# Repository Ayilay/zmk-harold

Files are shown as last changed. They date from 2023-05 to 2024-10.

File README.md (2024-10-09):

# Harold Keyboard

A fully-split fully-wireless keyboard that I made for myself. Powered by ZMK, a 750mAh LiPo, and an Seeeduino XIAO NRF52840.

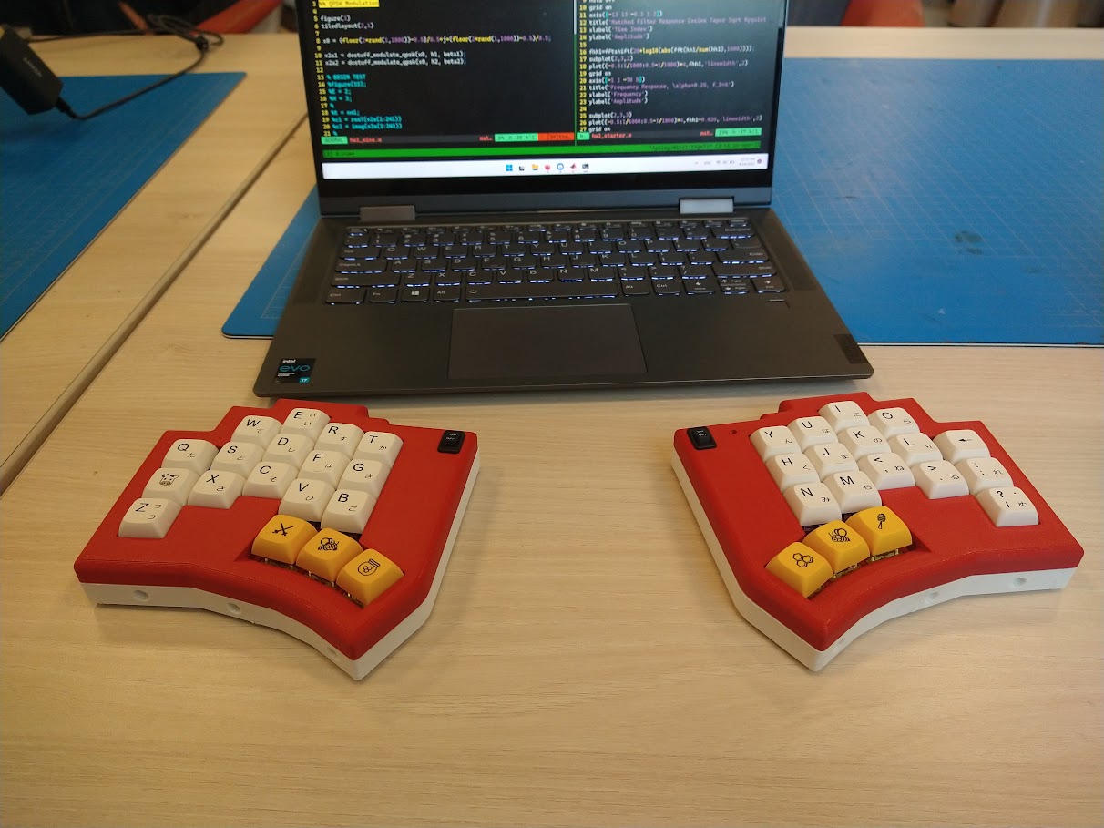
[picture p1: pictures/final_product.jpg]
Final Product


## Repository Files

`config` has the zmk config files.
`hardware/ergogen` has the [Ergogen](https://github.com/ergogen/ergogen) files that were used to generate PCB Layout.
`hardware/pcb` has the KiCAD PCB files.

## Pictures

This is my favorite use case: Comfy Coding
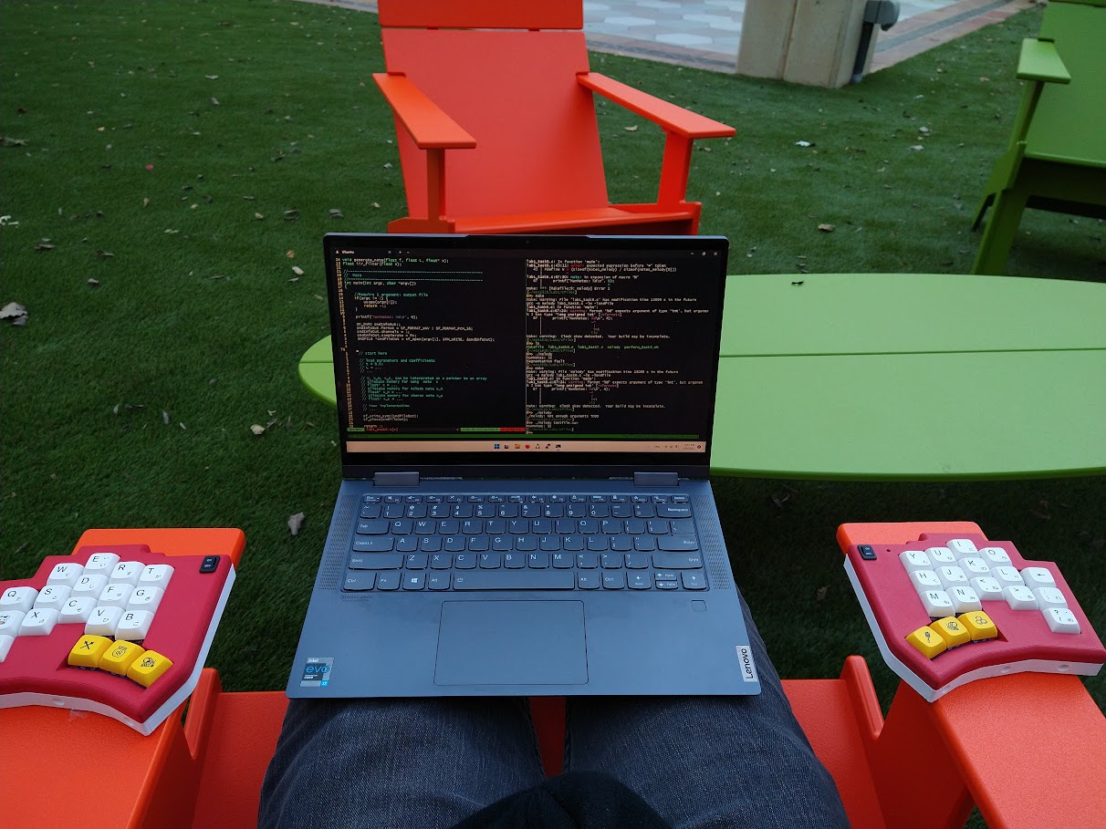
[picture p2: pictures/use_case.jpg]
Use Case


This is what it looks like under the hood:
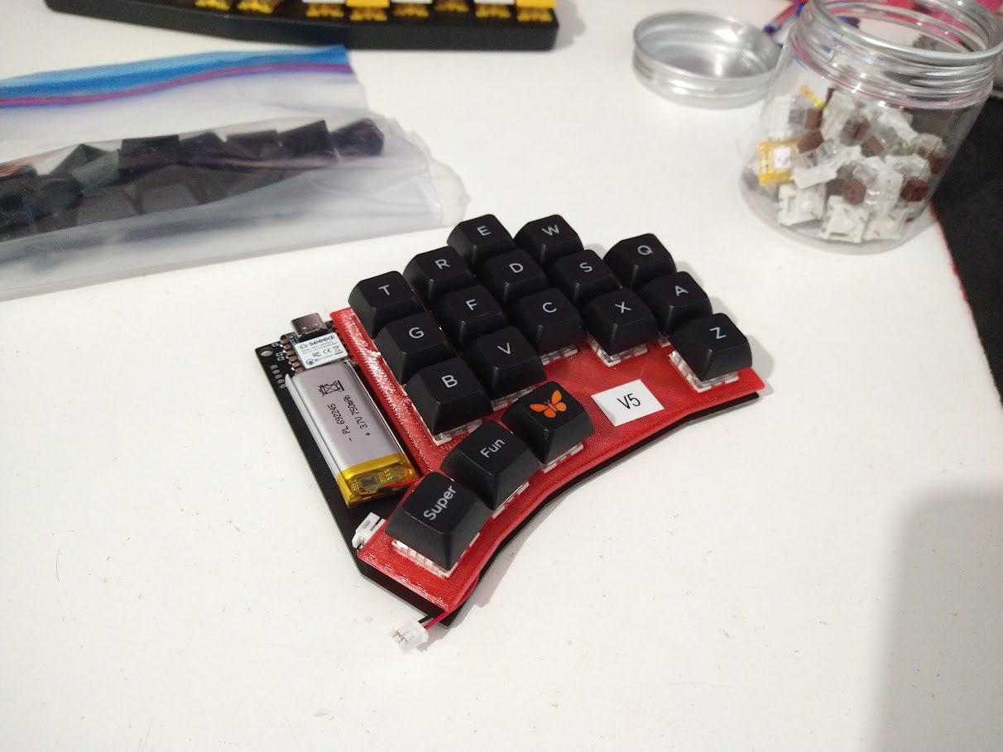
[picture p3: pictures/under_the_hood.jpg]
Under the hood


## FAQ

#### WOA That's so cool! You should sell these!
No. I made this keyboard to fill a very particular need.
This keyboard was highly customized for myself. There are plenty of other companies out there
with exceptional split wireless keyboards.

#### Doesn't the battery run out?
Many wireless keyboards I've seen use a dinky 250 mAh LiPo battery, because it's very small.
Luckily I was able to squeeze a 750 mAh battery into mine, and I can go up to a month without charging it.

#### It must have such high typing latency, it's Bluetooth!
Nope! The latency is so negligible that it may as well be wired. I can easily exceed 100WPM with no
discernible lag.

#### But you can't use it for gaming.
Wrong. I game with it all the time. I'm not a leet-pro-mlg gamer, I just game casually now and then.
Games like Team Fortress 2 and Portal, nothing crazy. Works perfectly fine.

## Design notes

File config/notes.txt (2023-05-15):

Stuff to add/fix:
 - Single/double quote
 - Quick language switching
 - Windows Explorer Nav
 - Close app
 - Nice app switcher
 - Bootloader mode
 - Eradicate uncomfortable pinkie key?
 - More comfortable forward slash
 - Emojis?
 - Mouse Keys?

 Things that are nice:
 - Ctrl + Alt mod-tap feels nice

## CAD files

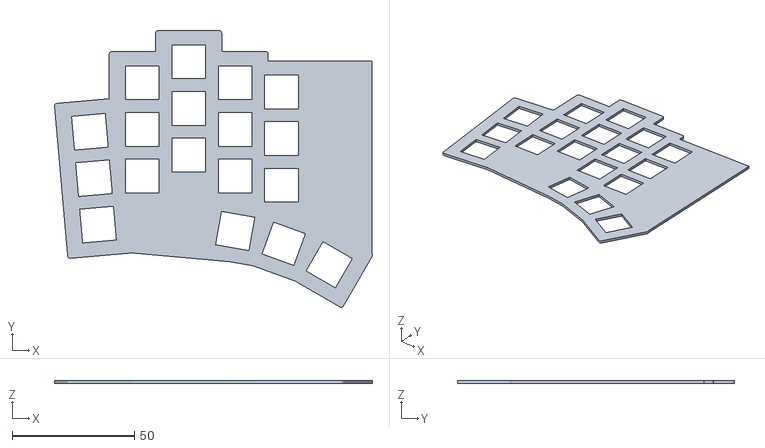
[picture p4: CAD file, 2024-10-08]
hardware/ergogen/outputs_v7/cases/plate_extrude.stl
130.0 x 113.2 x 1.20

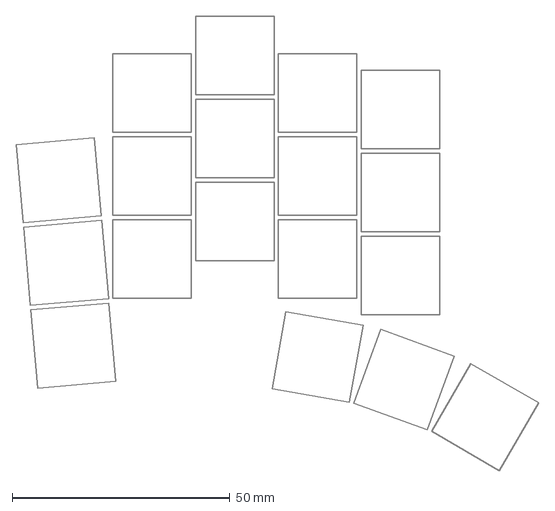
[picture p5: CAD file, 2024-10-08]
hardware/ergogen/outputs_v7/outlines/keycap_outlines.dxf
119.9 x 104.3 mm

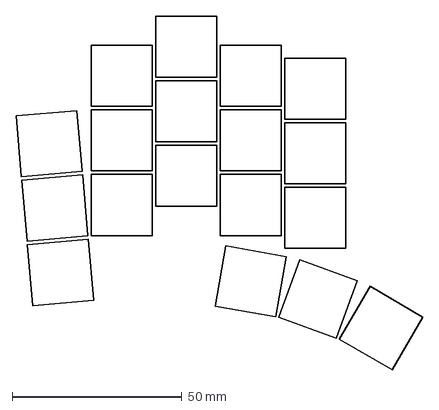
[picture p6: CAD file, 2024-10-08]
hardware/ergogen/outputs_v7/points/demo.dxf
119.9 x 104.3 mm

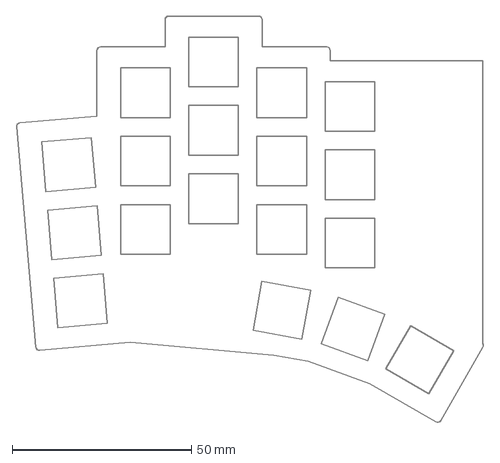
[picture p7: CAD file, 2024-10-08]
hardware/ergogen/outputs_v7/outlines/plate_debug.dxf
130.1 x 113.3 mm

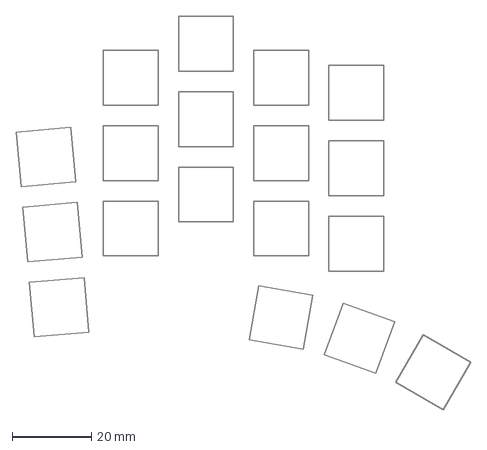
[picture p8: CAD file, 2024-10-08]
hardware/ergogen/outputs_v7/outlines/switch_cutouts.dxf
114.8 x 99.4 mm

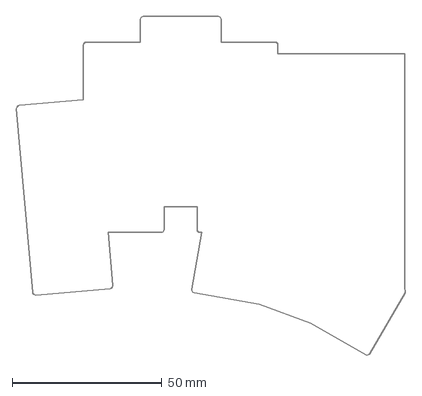
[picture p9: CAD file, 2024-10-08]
hardware/ergogen/outputs_v7/outlines/bare_switch_outline.dxf
130.1 x 113.3 mm

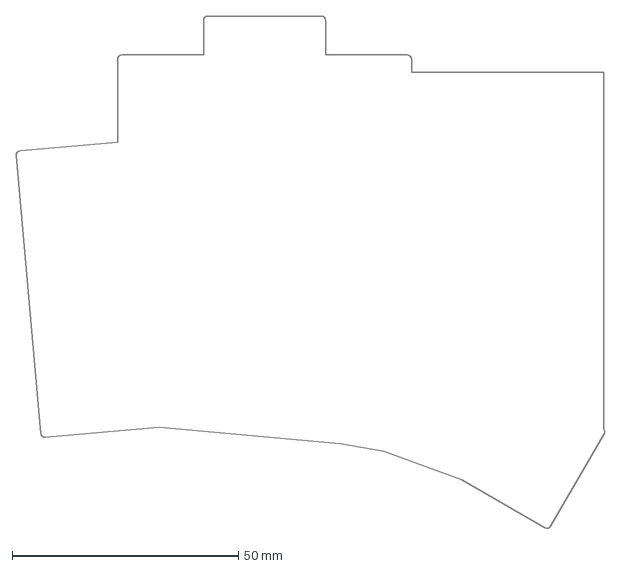
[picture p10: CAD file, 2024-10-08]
hardware/ergogen/outputs_v7/outlines/panel_outline.dxf
130.1 x 113.3 mm

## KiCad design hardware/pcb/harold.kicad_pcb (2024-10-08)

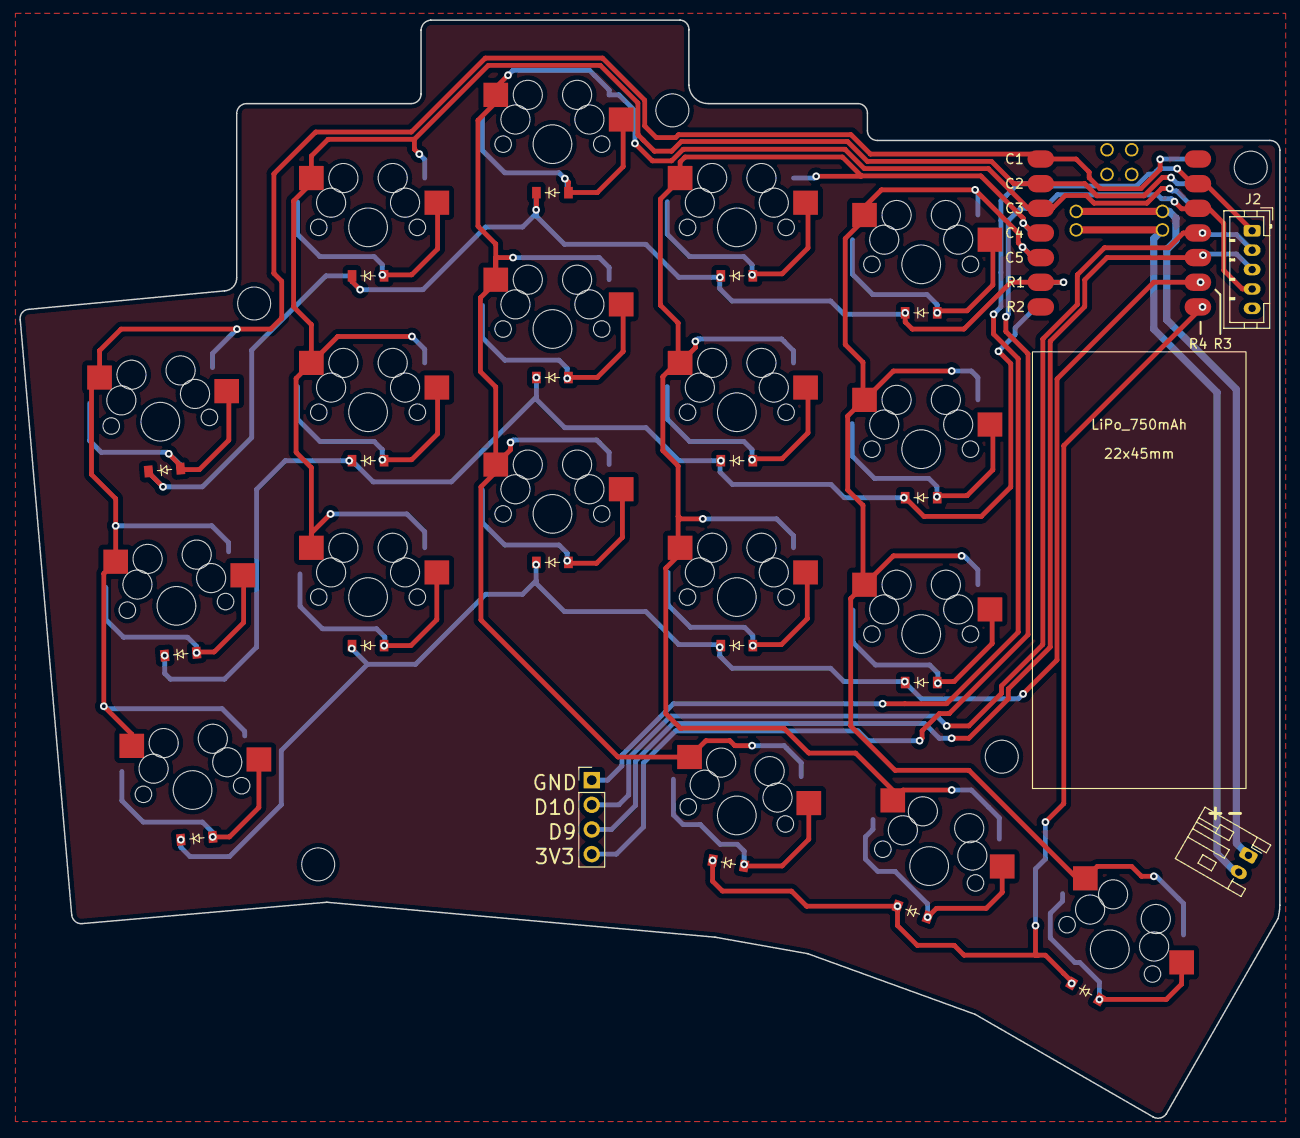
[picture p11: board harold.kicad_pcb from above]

Board: 2 copper layers, 129.8 x 113.2 mm, 39 parts (0 on the bottom side), 31 nets.

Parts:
BAT**: LiPo_750mAh
D1, D2, D3, D4, D5, D6, D7, D8, D9, D10, D11, D12, D13, D14, D15, D16, D17, D18: ComboDiode
J2: JST_PH_B5B-PH-K_1x05_P2.00mm_Vertical
MCU1: XiaoBLE_SMD
S1, S2, S3, S4, S5, S6, S7, S8, S9, S10, S11, S12, S13, S14, S15, S16, S17, S18: MX

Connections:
3V3: J2.4, MCU1.12
COL_Indx: MCU1.4, MCU1.11, S10.2, S11.2, S12.2, S17.2
COL_Innr: MCU1.5, MCU1.10, S13.2, S14.2, S15.2, S18.2
COL_Midd: MCU1.3, S7.2, S8.2, S9.2, S16.2
COL_Pink: MCU1.1, S1.2, S2.2, S3.2
COL_Ring: MCU1.2, S4.2, S5.2, S6.2
D9: J2.3, MCU1.5, MCU1.10
D10: J2.2, MCU1.4, MCU1.11
GND: J2.1, MCU1.13
ROW_Bot: D1.1, D4.1, D7.1, D10.1, D13.1, MCU1.6, MCU1.9
ROW_Home: D2.1, D5.1, D8.1, D11.1, D14.1, MCU1.7, MCU1.8
ROW_Thumb: D16.1, D17.1, D18.1, MCU1.7, MCU1.8
ROW_Top: D3.1, D6.1, D9.1, D12.1, D15.1, MCU1.6, MCU1.9
homey_thumb_row: D17.2, S17.1
index_bottom: D10.2, S10.1
index_home: D11.2, S11.1
index_top: D12.2, S12.1
inner_bottom: D13.2, S13.1
inner_home: D14.2, S14.1
inner_top: D15.2, S15.1
middle_bottom: D7.2, S7.1
middle_home: D8.2, S8.1
middle_top: D9.2, S9.1
pinky_bottom: D1.2, S1.1
pinky_home: D2.2, S2.1
pinky_top: D3.2, S3.1
reachy_thumb_row: D18.2, S18.1
ring_bottom: D4.2, S4.1
ring_home: D5.2, S5.1
ring_top: D6.2, S6.1
tucky_thumb_row: D16.2, S16.1

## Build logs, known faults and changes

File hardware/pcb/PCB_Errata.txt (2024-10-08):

Version 1:
[ ] FATAL:     Battery Conn is NOT SYMMETRIC
[ ] IMPORTANT: Seeduino Pin 7 on Front layer unconnected
[ ] IMPORTANT: No on/off switch *facepalm
[ ] IMPORTANT: Mount Holes are 3.4mm diam, not 1.7! KiCad uses Radius not Diameter
[ ] UX:        Pinkie stagger too aggressive; 
                  bottom-key very uncomfortable
[ ] AESTHETIC: Battery +/- silk is wonky
[ ] AESTHETIC: Row/Col silk on Back layer is not aligned

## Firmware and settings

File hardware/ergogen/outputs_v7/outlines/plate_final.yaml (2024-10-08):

models:
    export:
        models:
            a:
                models:
                    a:
                        models: {}
                        origin:
                            - 0
                            - 0
                    b:
                        models:
                            a:
                                models:
                                    a:
                                        models:
                                            a:
                                                models:
                                                    a:
                                                        models: {}
                                                        origin:
                                                            - 0
                                                            - 0
                                                    b:
                                                        models:
                                                            a:
                                                                models: {}
                                                                origin:
                                                                    - 0
                                                                    - 0
                                                            b:
                                                                models:
                                                                    a:
                                                                        models:
                                                                            a:
                                                                                models:
                                                                                    a:
                                                                                        models:
                                                                                            a:
                                                                                                models:
                                                                                                    a:
                                                                                                        models:
                                                                                                            a:
                                                                                                                models:
                                                                                                                    a:
                                                                                                                        models:
                                                                                                                            a:
                                                                                                                                models:
                                                                                                                                    a:
                                                                                                                                        models:
                                                                                                                                            a:
                                                                                                                                                models:
                                                                                                                                                    a:
                                                                                                                                                        models:
                                                                                                                                                            a:
                                                                                                                                                                models:
                                                                                                                                                                    a:
                                                                                                                                                                        models:
                                                                                                                                                                            a:
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

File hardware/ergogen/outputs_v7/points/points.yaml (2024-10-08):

matrix_pinky_bottom:
    x: 0
    'y': 0
    r: 5
    meta:
        shift:
            - 0
            - 0
        rotate: 0
        padding: 19.05
        width: 1
        height: 1
        skip: false
        asym: both
        footprints:
            mx_hotswap:
                type: mx
                nets:
                    from: '=colrow'
                    to: '=colnet'
                params:
                    reverse: true
                    hotswap: true
                    keycaps: false
            diode:
                type: diode
                nets:
                    from: '=colrow'
                    to: '=rownet'
                anchor:
                    shift:
                        - 0
                        - -5
        colnet: COL_Pink
        rownet: ROW_Bot
        name: matrix_pinky_bottom
        colrow: pinky_bottom
        col: &ref_0
            rotate: 5
            key:
                colnet: COL_Pink
            stagger: 0
            spread: 0
            origin:
                - 0
                - 0
            rows: {}
            name: pinky
        row: bottom
matrix_pinky_home:
    x: -1.6603169
    'y': 18.977509
    r: 5
    meta:
        shift:
            - 0
            - 0
        rotate: 0
        padding: 19.05
        width: 1
        height: 1
        skip: false
        asym: both
        footprints:
            mx_hotswap:
                type: mx
                nets:
                    from: '=colrow'
                    to: '=colnet'
                params:
                    reverse: true
                    hotswap: true
                    keycaps: false
            diode:
                type: diode
                nets:
                    from: '=colrow'
                    to: '=rownet'
                anchor:
                    shift:
                        - 0
                        - -5
        colnet: COL_Pink
        rownet: ROW_Home
        name: matrix_pinky_home
        colrow: pinky_home
        col: *ref_0
        row: home
matrix_pinky_top:
    x: -3.3206338
    'y': 37.955018
    r: 5
    meta:
        shift:
            - 0
            - 0
        rotate: 0
        padding: 19.05
        width: 1
        height: 1
        skip: false
        asym: both
        footprints:
            mx_hotswap:
                type: mx
                nets:
                    from: '=colrow'
                    to: '=colnet'
                params:
                    reverse: true
                    hotswap: true
                    keycaps: false
            diode:
                type: diode
                nets:
                    from: '=colrow'
                    to: '=rownet'
                anchor:
                    shift:
                        - 0
                        - -5
        colnet: COL_Pink
        rownet: ROW_Top
        name: matrix_pinky_top
        colrow: pinky_top
        col: *ref_0
        row: top
matrix_ring_bottom:
    x: 18.0860318
    'y': 19.8833141
    r: 0
    meta:
        shift:
            - 0
            - 0
        rotate: 0
        padding: 19.05
        width: 1
        height: 1
        skip: false
        asym: both
        footprints:
            mx_hotswap:
                type: mx
                nets:
                    from: '=colrow'
                    to: '=colnet'
                params:
                    reverse: true
                    hotswap: true
                    keycaps: false
            diode:
                type: diode
                nets:
                    from: '=colrow'
                    to: '=rownet'
                anchor:
                    shift:
                        - 0
                        - -5
        colnet: COL_Ring
        rownet: ROW_Bot
        name: matrix_ring_bottom
        colrow: ring_bottom
        col: &ref_1
            rotate: -5
            origin:
                - -9
                - -9
            stagger: 19.05
            spread: 19
            key:
                colnet: COL_Ring
            rows: {}
            name: ring
        row: bottom
matrix_ring_home:
    x: 18.0860318
    'y': 38.933314100000004
    r: 0
    meta:
        shift:
            - 0
            - 0
        rotate: 0
        padding: 19.05
        width: 1
        height: 1
        skip: false
        asym: both
        footprints:
            mx_hotswap:
                type: mx
                nets:
                    from: '=colrow'
                    to: '=colnet'
                params:
                    reverse: true
                    hotswap: true
                    keycaps: false
            diode:
                type: diode
                nets:
                    from: '=colrow'
                    to: '=rownet'
                anchor:
                    shift:
                        - 0
                        - -5
        colnet: COL_Ring
        rownet: ROW_Home
        name: matrix_ring_home
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

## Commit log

2023-03-06 tuned HRM win key better for lang switching
2024-10-08 Add readme and pictures
    [bare_switch_outline.dxf, demo.dxf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]
